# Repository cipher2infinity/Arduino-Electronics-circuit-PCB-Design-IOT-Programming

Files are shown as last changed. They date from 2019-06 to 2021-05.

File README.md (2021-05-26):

# Arduino : Electronics circuit, PCB Design & IOT Programming

You can check the course curriculum on our [WEBSITE](https://www.cipher2infinity.com/)

## Content
* Images of Datalogger
* Hardware design files and firmware files for Industrial DataLogger.
* Examples codes used in demos of all the sections of datalogger.
* hardware descreption section includes descreptions for all the hardware blocks of datalogger. 
* Libraries used in demo code

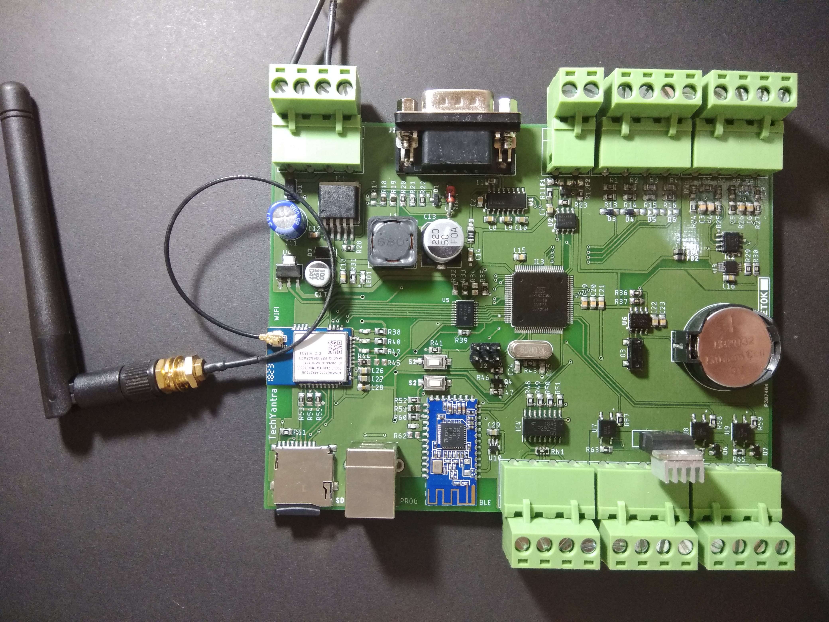
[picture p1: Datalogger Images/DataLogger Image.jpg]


## Introduction
Please check the following links for demostration of Datalogger

1. This [video](https://drive.google.com/open?id=1AglGJTn_O3K_O5rFmPPeSSnq5-zFRN2F) describes the entire PCB of Industrial Datalogger

2. This [video](https://drive.google.com/open?id=1-QjOal9vDFr6C30vdyRp-lrAA95-3nSr) gives the demostration of each and every inetrface of Industrial Datalogger

## Features
* SMPS (5V)
* LDO Regulator (3.3v)
* Relay Driver										 (2 CH)
* DC Motor Speed Controller
* 0-10 V Digital Input 					 (4 CH)
* 0-10 V Analog Input 						 (4 CH)
* 4-20 mA Receiver								 (2 CH)
* Real Time Clock
* Bluetooth Low Energy 
* WiFi Module
* SD Card Module
* RS232 Interface
* RS485 Interface
* 6 Pin ICSP Headers
* Serial Programming using UART0

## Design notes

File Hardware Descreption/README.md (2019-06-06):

ALL the sections of the datalogger are described in brief also Schematic files are included.

* Power Supply Circuit
* Atmega256 Circuit.
* DC Motor Speed Controller Circuit
* 0-10 V Digital Input Circuit
* RS485 Interface Circuit
* Relay Driver Circuit
* 0-10 V Analog Input Circuit
* RTC Circuit 
* 4-20 mA circuit
* BLE Module Circuit
* WiFi Module Circuit
* SD Card Circuit
* RS232 Interface Circuit
* Analog and Digital Isolation Circuit

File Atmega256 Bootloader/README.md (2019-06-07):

# Software to Program bootloader

You will need AVRDUDESS software to program bootloader in ATMEGA256.

Connect your ATMEGA256 to USBASP programmer, Later in AVRDUDESS software select the bootloader file also fill the fuse bytes mentioned in 
board.txt file for ATMEGA2560 (Arduino Mega) and later press the program button.

Now your microcontroller is programmed with bootloader and it is ready to use with arduino IDE and its libraries.

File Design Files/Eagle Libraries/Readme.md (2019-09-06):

Eagle libraries.zip file includes the (Eagle footprint and symbol) libraries that are downloaded from external site.

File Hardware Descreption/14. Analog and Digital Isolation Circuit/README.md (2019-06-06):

# Analog and Digital Isolation Circuit Descreption

1. FB1 and FB2 are the ferrite breads which are used to supress the noise comming from 5v to analog VCC and Analog ground to digital ground

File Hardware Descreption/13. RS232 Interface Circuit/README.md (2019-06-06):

# RS232 Interface Circuit Descreption

1. MAX232 from Maxim Corp. is a line driver IC for RS232 Interface, MAX232_TX and MAX232_RX is connected to Rx and TX pins of UART1 on ATMEGA256.
2. T1Out and R1In is connected to DB9 connector.
3. C2 and C8 are used to double the voltage from 5v to 10 volt which is in RS232 standerd range for logic '0'.
4. C10 and C9 are used to invert the voltage from +10 to -10 volt which is basically logic '1' for RS232 standerd.

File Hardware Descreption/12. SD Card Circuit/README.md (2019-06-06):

# SD Card Circuit

1. SN74LVC245 is a 8 channel transiever IC which is used to convert the voltage from 5v to 3.3v as WiFi module works on 3.3v.
2. SD Card works on 3.3 V so voltage on SPI pins are first drop down to 3.3v by using voltage level converter IC.
3. SD detect pin is pulled to 3.3v using a 10k pull up resistor to provide default logic high on SD detect pin of SD card holder.
4. This will allow us to detect whether SD card is present or not.
5. BSS138 MOSFET is used to convert the voltage on MISO pin.

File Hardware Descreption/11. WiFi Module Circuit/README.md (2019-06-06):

# WiFi Module Circuit Descreption

1. SN74LVC245 is a 8 channel transiever IC which is used to convert the voltage from 5v to 3.3v as WiFi module works on 3.3v.
2. ATWINC1510 wifi module is used for industrial IOT related applications, like to upload the datalogger parameters to web based data visualization website.
3. Led 1 shows the status whether WiFi is connected to the WiFi network or not.
4. Led 2 blinks when WiFi module recieves the data or transmits the data.
5. Led 3 light up when their is some hardware related fault.
6. BSS138 MOSFET is used to convert the voltage on MISO pin.

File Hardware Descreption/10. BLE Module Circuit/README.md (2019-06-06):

1. Between TX pin of microcontroller and Rx pin of BLE module a SN74LVC1G125 buffer is connecetd this is done to step down the voltage from 5v to 3.3v as BLE works on 3.3v.
2. Tx pin of BLE is connected to Rx pin of Atmega256, basically BLE is conneted on UART1 of Atmega256.
3. A led with current limiting resistor is connected on pin 24 of BLE, this will let you know the status of BLE whether BLE is connected or not.
4. Key pin is pulled up to 3.3v using a 10k resistor this will provide default logic high on key pin. Whnever key pin will be pulled down to ground the BLE will disconnect the connection from connected device.

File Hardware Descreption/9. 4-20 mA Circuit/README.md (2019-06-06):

# 4-20 mA Circuit Descreption

1. 100 ohm resistor after the diode are used to convert the current range to voltage range (4-20 mA to 0.4 to 2V).
2. The converted voltage is provided to the diffrential amplifier (Gain = 1) basically it is acting as a buffer. Diffrential amplifier is used to provide the impedance matching between the 4-20 mA sensor output and ADC IC's input.
3. Schottky diodes (SS14) on inverting and non inverting terminals are used to protect the OPAMP pins from overvoltage.
4. Diodes are connected before 100 ohm resistor to avoid readings when sensor is connected in wrong direction.
5. 0.1 uf capacitors are connceted on input pin and output pin of OPAMP this is done to avoid noise on input and output of OPAMP.
6. Output of OPAMP is connected to analog channel 1 and analog channel 2 of ADS1115 IC to read analog output of opamps.
7. ADS1115's I2C pins are connected to I2C pins of microcontroller to read the data for anlog channel 0 and 1.
8. ADDR pin is connected to ground this is done to assign I2C address to the IC.

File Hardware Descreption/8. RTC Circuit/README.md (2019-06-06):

# RTC Circuit Descreption

1. DS1307 RTC IC is responcible for the realtime clock feature of datalogger.
2. 32.768 KHz crystal is connected on X1 and X2 pin of RTC IC, to provide clock to the IC.
3. A CMOS battery adapter is connected on VBATT pin this will keep the clock running even if the power to datalogger is cutoff.
4. Combination of 0.1uf and 10uf capacitor is used to eliminate the noise from power supply that will avoid the data of RTC being corrupted.
5. 2.2k pull up resistors are provided to SCL and SDA pins of I2C interface this will avoid the open drain condition of the I2C hardware and will provide by default logic high on I2C pins if they are not pulled down.

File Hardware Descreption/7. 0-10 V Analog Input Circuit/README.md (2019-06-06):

# 0-10 V Analog Input Circuit Descreption

1. Pair of resistor R1-R13, R2-R14, R3-R15, R4-R16 are used to scale down the voltage (i.e. 10v will be converted to 5v) and later it is provided to the analog input pins of Atmega256.
2. AIN2, AIN3, AIN4, AIN5 are connected to A12, A13, A14 and A15 which are pins of Arduino Mega.
3. 5.1 V zener diodes are used to supress the applied input voltage if it is greater than 10v, that will protect the analog pins of Atmega256.

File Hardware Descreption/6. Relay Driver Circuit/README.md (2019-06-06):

# Relay Driver Circuit Descreption
1. This circuit is used to control the relay which will be connected externally.
2. This circuit uses EL357 optocoupler IC which is used to isolate the microcontroller pin from the output circuitry.
4. BC817 is a NPN transistor which is used to drive the relay, it can provide maximum of 600 mA which is more than sufficient to drive a relay.
5. SS14 schottky diode is used to provide the protection form back EMF.
6. R64 and R65 are used to limit the current flowing from the base of BC817 transistor.
7. R58 and R59 are the current limiting resistor for the led of optocoupler.
8. Relay_1 and Relay_2 pins are connected to GPIO pin of the microcontroller.

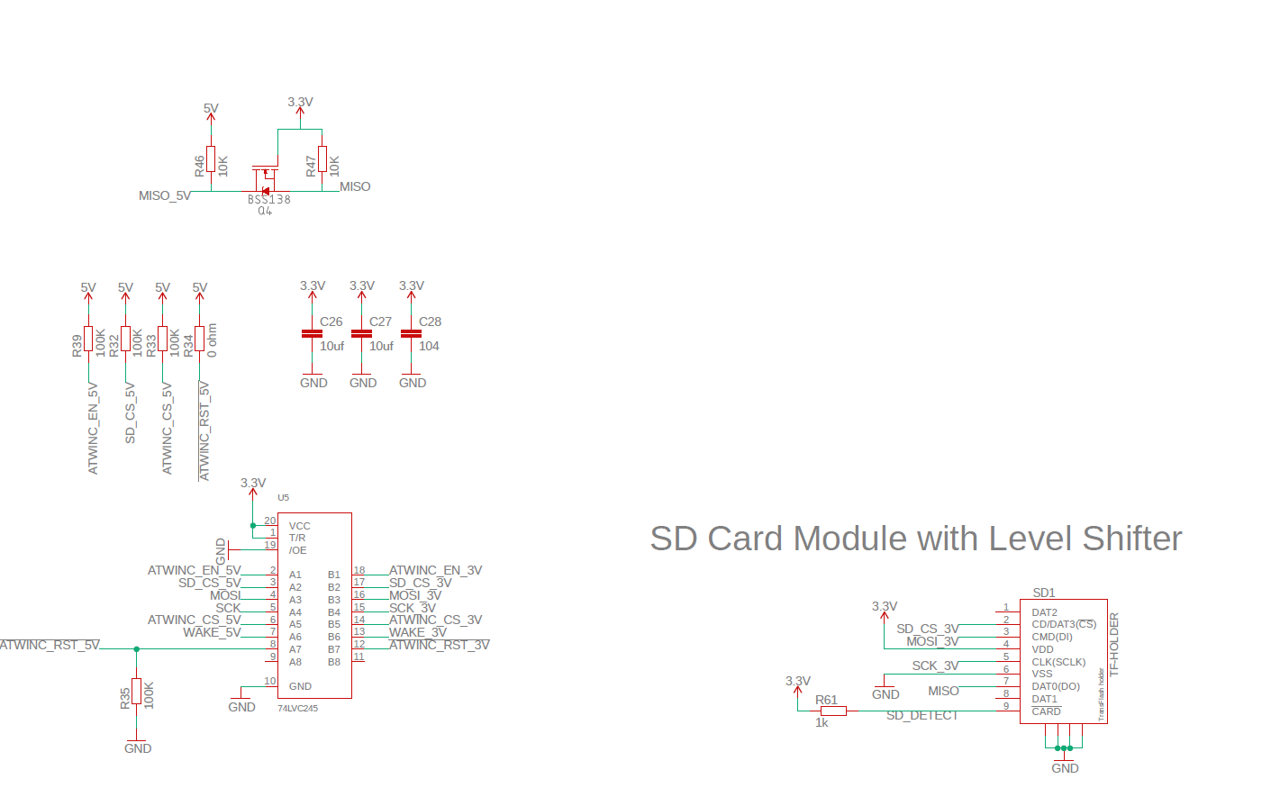
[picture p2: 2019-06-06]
Hardware Descreption/12. SD Card Circuit/SD Card Circuit.png

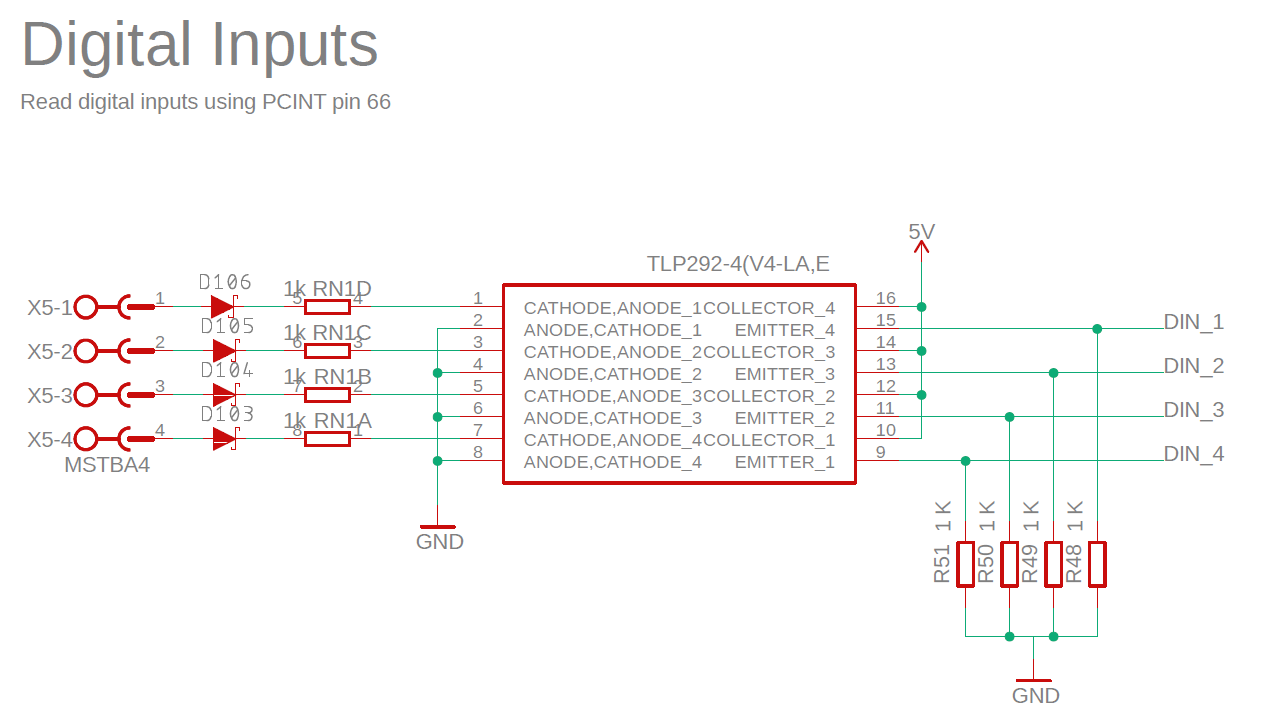
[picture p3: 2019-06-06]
Hardware Descreption/4. 0-10 V Digital Inputs Circuit/0-10 V Digital Input Circuit.png

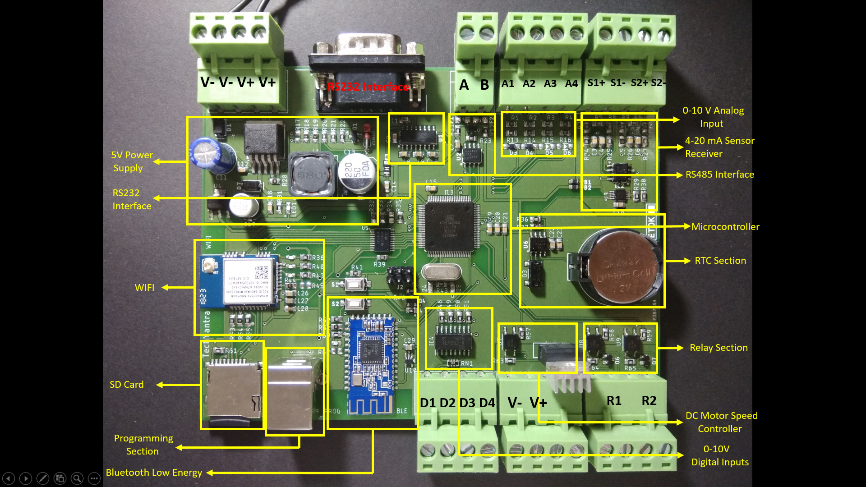
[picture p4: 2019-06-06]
Datalogger Images/Data Logger Board overview.png

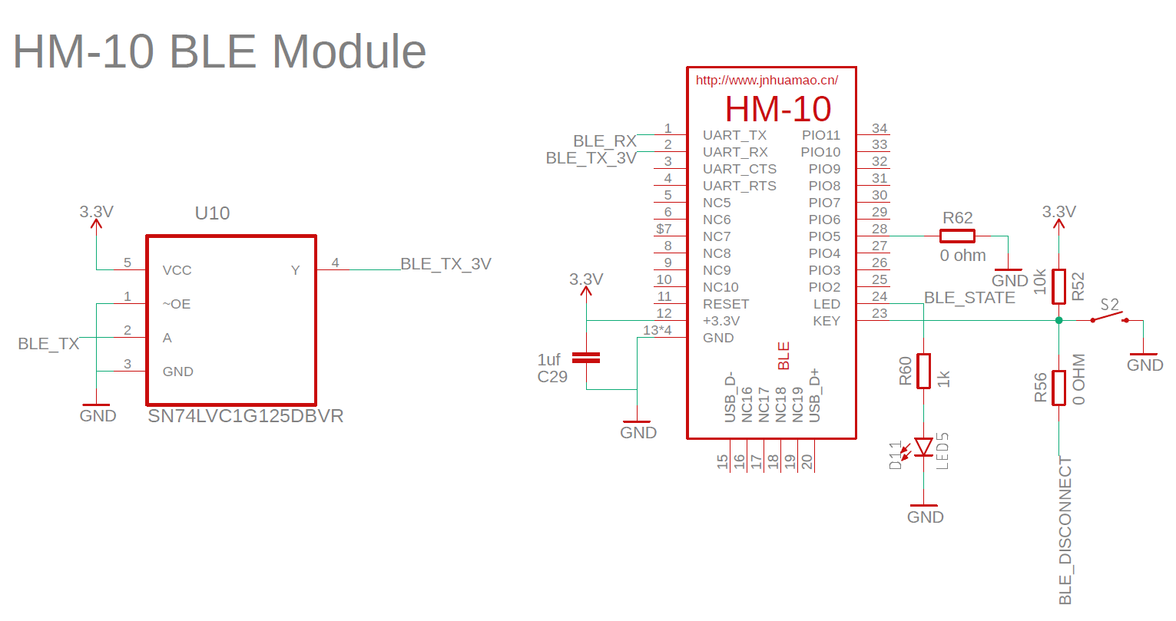
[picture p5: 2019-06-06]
Hardware Descreption/10. BLE Module Circuit/BLE Module Circuit.png

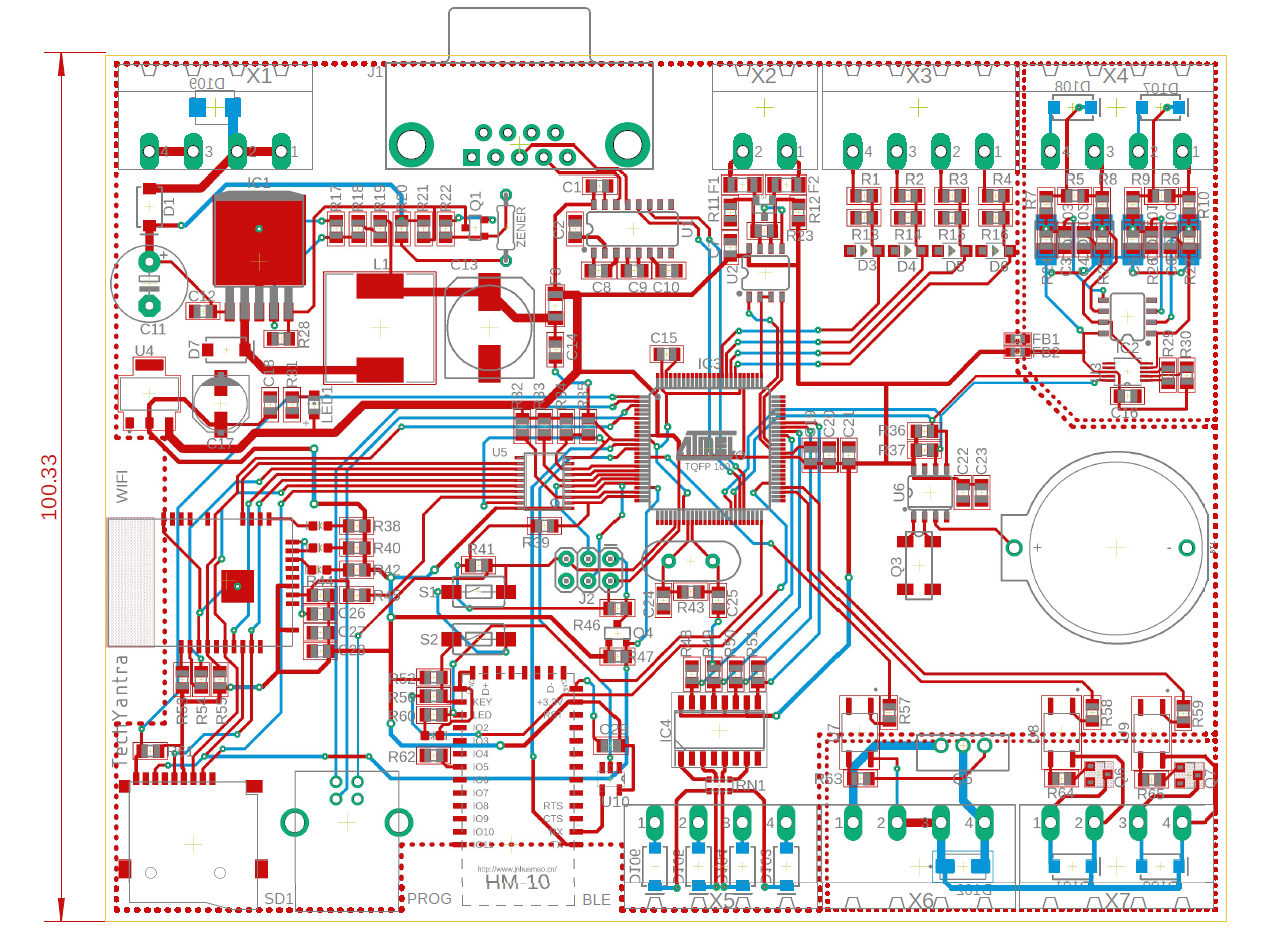
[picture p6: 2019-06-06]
Design Files/DataLogger Layout.png

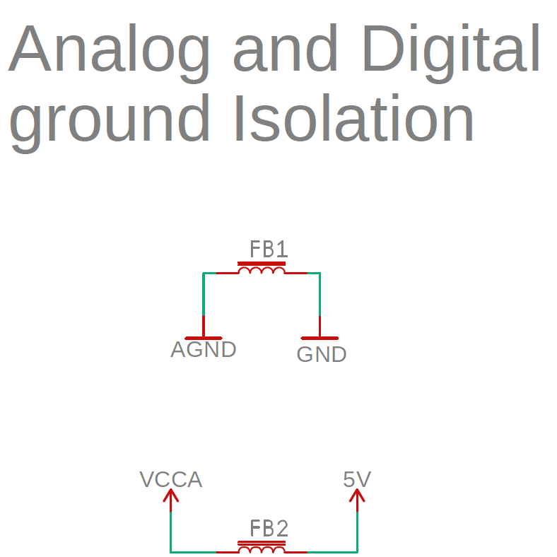
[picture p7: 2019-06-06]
Hardware Descreption/14. Analog and Digital Isolation Circuit/Analog and Digital Isolation.png

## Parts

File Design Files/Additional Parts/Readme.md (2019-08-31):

* Following components or module are used during the course

# Modules

* USB to TTL converter
* RS232 to TTL converter
* RS485 to TTL converter
* USBASP programmer
* 10 k potentiometer
* DS1307 RTC module
* ADS1115 16 bit ADC module
* 12v DC motor
* 12v Relay
* Submercible pump
* Salae Logic Analyzer
* SD card
* Multimeter
* 4-20mA transmitter

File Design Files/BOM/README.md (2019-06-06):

* Bill of material file includes all the components used in this datalogger

# Main IC's Used on Datalogger

* LM2596-5.0 SMPS
* AMS1117-3.3 LDO Regulator
* ATMEGA2560 Microcontroller
* EL357 Optocoupler
* TLP492-4 4 Channel optocoupler 
* MAX485 RS485 Driver
* DS1307 RTC
* ADS1115 16 bit 4 channel ADC
* LM358 OPAMP
* SN74LVC1G125 Single channel buffer
* HM-10 BLE Module
* SN74LVC1G245 Octal transievr
* ATWINC1510 WiFi Module
* MAX232 Line Driver

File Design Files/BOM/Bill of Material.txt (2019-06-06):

Partlist exported from E:/Projects/Data Logger V3.0/Data Logger V3.0/Data Logger V3.1.sch at 6/3/2019 9:30 AM

Part   Value                               Device                              Package                      Description                                                                                                                                                                                                                                       AVAILABILITY DESCRIPTION                                                                                      HEIGHT MANUFACTURER_NAME       MANUFACTURER_PART_NUMBER MF                          MOUSER_PART_NUMBER MOUSER_PRICE-STOCK                                                   MP               MPN                            OC_FARNELL OC_NEWARK PACKAGE                          PRICE PROD_ID     RS_PART_NUMBER RS_PRICE-STOCK                                               SF_SKU    SPICEMODEL SPICEPREFIX VALUE        
BLE    HM-10-BOARD                         HM-10-BOARD                         26.9X13X2.2_BOARD            HM Bluetooth module use TI CC2540 or CC2541, Master and slave roles in one, transmission version and remote control version and PIO state acquisition functions in one, Support the AT command modify module parameters, Convenient and flexible.                                                                                                                                                                                                                                                                                                                                                                                                                                                                                                                                             
BT1                                        BATTERY-20MM_PTH                    BATTCOM_20MM_PTH             Battery - Single Cell                                                                                                                                                                                                                                                                                                                                                                                                                                                                                                                                                                                                                                   BATT-09031                                                                              PRT-00783                                     
C1     0.1uf                               C-EUC0805                           C0805                        CAPACITOR, European symbol                                                                                                                                                                                                                                                                                                                                                                                                                                                                                                                                                                                                                                                                                                                                           C                        
C2     0.1uf                               C-EUC0805                           C0805                        CAPACITOR, European symbol                                                                                                                                                                                                                                                                                                                                                                                                                                                                                                                                                                                                                                                                                                                                           C                        
C3     0.1uf                               C-EUC0805                           C0805                        CAPACITOR, European symbol                                                                                                                                                                                                                                                                                                                                                                                                                                                                                                                                                                                                                                                                                                                                           C                        
C4     0.1uf                               C-EUC0805                           C0805                        CAPACITOR, European symbol                                                                                                                                                                                                                                                                                                                                                                                                                                                                                                                                                                                                                                                                                                                                           C                        
C5     0.1uf                               C-EUC0805                           C0805                        CAPACITOR, European symbol                                                                                                                                                                                                                                                                                                                                                                                                                                                                                                                                                                                                                                                                                                                                           C                        
C6     0.1uf                               C-EUC0805                           C0805                        CAPACITOR, European symbol                                                                                                                                                                                                                                                                                                                                                                                                                                                                                                                                                                                                                                                                                                                                           C                        
C7     104                                 C-EUC0805                           C0805                        CAPACITOR, European symbol                                                                                                                                                                                                                                                                                                                                                                                                                                                                                                                                                                                                                                                                                                                                           C                        
C8     0.1uf                               C-EUC0805                           C0805                        CAPACITOR, European symbol                                                                                                                                                                                                                                                                                                                                                                                                                                                                                                                                                                                                                                                                                                                                           C                        
C9     0.1uf                               C-EUC0805                           C0805                        CAPACITOR, European symbol                                                                                                                                                                                                                                                                                                                                                                                                                                                                                                                                                                                                                                                                                                                                           C                        
C10    0.1uf                               C-EUC0805                           C0805                        CAPACITOR, European symbol                                                                                                                                                                                                                                                                                                                                                                                                                                                                                                                                                                                                                                                                                                                                           C                        
C11    470uf                               CPOL-USE5-8.5                       E5-8,5                       POLARIZED CAPACITOR, American symbol                                                                                                                                                                                                                                                                                                                                                                                                                                                                                                                                                                                                                                                                                                                                                          
C12    104                                 C-EUC0805                           C0805                        CAPACITOR, European symbol                                                                                                                                                                                                                                                                                                                                                                                                                                                                                                                                                                                                                                                                                                                                           C                        
C13    220uf                               CPOL-US150CLZ-1014                  150CLZ-1014                  POLARIZED CAPACITOR, American symbol                                                                                                                                                                                                                                                                                                                                                                                                                                                                                                                                                                                                                                                                                                                                                          
C14    104                                 C-EUC0805                           C0805                        CAPACITOR, European symbol                                                                                                                                                                                                                                                                                                                                                                                                                                                                                                                                                                                                                                                                                                                                           C                        
C15    104                                 C-EUC0805                           C0805                        CAPACITOR, European symbol                                                                                                                                                                                                                                                                                                                                                                                                                                                                                                                                                                                                                                                                                                                                           C                        
C16    0.1uf                               C-EUC0805                           C0805                        CAPACITOR, European symbol                                                                                                                                                                                                                                                                                                                                                                                                                                                                                                                                                                                                                                                                                                                                           C                        
C17    100uF                               100UF-POLAR-25V-20%(ELEC)           PANASONIC_D                  100µF polarized capacitors                                                                                                                                                                                                                                                                                                                                                                                                                                                                                                                                                                                                                              CAP-12547                                                                                                                100uF        
C18    104                                 C-EUC0805                           C0805                        CAPACITOR, European symbol                                                                                                                                                                                                                                                                                                                                                                                                                                                                                                                                                                                                                                                                                                                                           C                        
C19    104                                 C-EUC0805                           C0805                        CAPACITOR, European symbol                                                                                                                                                                                                                                                                                                                                                                                                                                                                                                                                                                                                                                                                                                                                           C                        
C20    104                                 C-EUC0805                           C0805                        CAPACITOR, European symbol                                                                                                                                                                                                                                                                                                                                                                                                                                                                                                                                                                                                                                                                                                                                           C                        
C21    104                                 C-EUC0805                           C0805                        CAPACITOR, European symbol                                                                                                                                                                                                                                                                                                                                                                                                                                                                                                                                                                                                                                                                                                                                           C                        
C22    10uf                                C-EUC0805                           C0805                        CAPACITOR, European symbol                                                                                                                                                                                                                                                                                                                                                                                                                                                                                                                                                                                                                                                                                                                                           C                        
C23    104                                 C-EUC0805                           C0805                        CAPACITOR, European symbol                                                                                                                                                                                                                                                                                                                                                                                                                                                                                                                                                                                                                                                                                                                                           C                        
C24    104                                 C-EUC0805                           C0805                        CAPACITOR, European symbol                                                                                                                                                                                                                                                                                                                                                                                                                                                                                                                                                                                                                                                                                                                                           C                        
C25    104                                 C-EUC0805                           C0805                        CAPACITOR, European symbol                                                                                                                                                                                                                                                                                                                                                                                                                                                                                                                                                                                                                                                                                                                                           C                        
C26    10uf                                C-EUC0805                           C0805                        CAPACITOR, European symbol                                                                                                                                                                                                                                                                                                                                                                                                                                                                                                                                                                                                                                                                                                                                           C                        
C27    10uf                                C-EUC0805                           C0805                        CAPACITOR, European symbol                                                                                                                                                                                                                                                                                                                                                                                                                                                                                                                                                                                                                                                                                                                                           C                        
C28    104                                 C-EUC0805                           C0805                        CAPACITOR, European symbol                                                                                                                                                                                                                                                                                                                                                                                                                                                                                                                                                                                                                                                                                                                                           C                        
C29    1uf                                 C-EUC0805                           C0805                        CAPACITOR, European symbol                                                                                                                                                                                                                                                                                                                                                                                                                                                                                                                                                                                                                                                                                                                                           C                        
D1     3A/40V/500mV                        DIODE-SCHOTTKY-B340A                SMA-DIODE                    Schottky diode                                                                                                                                                                                                                                                                                                                                                                                                                                                                                                                                                                                                                                          DIO-09886                                                                                                                3A/40V/500mV 
D2     SM712                               CDSOT23-SM712                       SOT-23-3                     Bourns CDSOT23-SM712                                                                                                                                                                                                                              Unavailable   Diode, Smt Tvs Array, 7vrwm & 12vrwm, Sot23 Package                                                                                                     Bourns                                                                                                              CDSOT23-SM712                                                        SOT-23 Bourns                    None
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

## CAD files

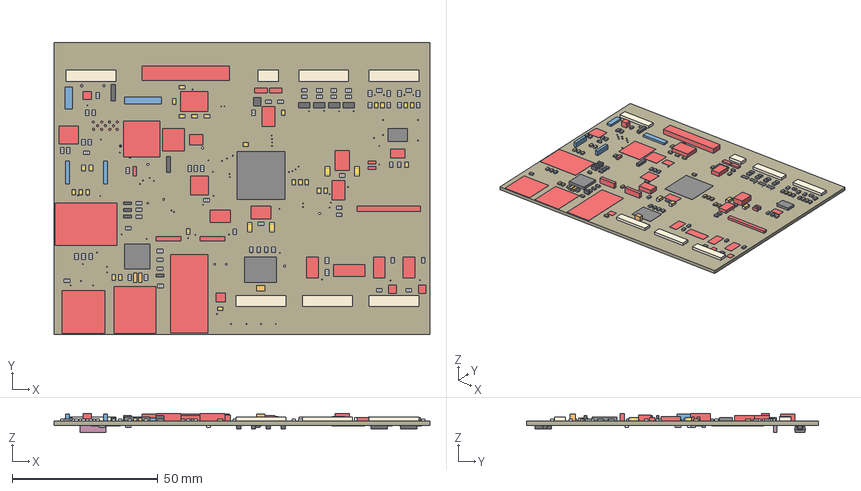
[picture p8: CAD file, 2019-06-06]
Design Files/Mechanical Design Files/Data Logger V2.stp
129.2 x 100.3 x 6.68 mm
Board
HM-10-BOARD
22p x 4
SMBJ26CA
SM712
SS14 x 4
ATMEGA2560-16AU
68uh
3.3uh
BSS138
TRANSISTOR-NPN x 2
16M
1 K x 44
0ohm x 26
TF-HOLDER
LM2596SX-ADJ/NOPB
AMS1117-3.3
74LVC245
ADS1115IDGST
SN74LVC1G125DBVR x 2
ATWINC1500_MR210PB
32.768kHz
MINISMDC050F-2
TIP120
M7
EL357N(A)(TA)-G x 3
TLP292-4(V4-LA,E
SMD-DIODE-ZENER-5.1V-500MW(SOD-123) x 4
BATTCOM_20MM_PTH
470uf
220uf
100uF x 2
3A/40V/500mV x 10
GREEN x 4
6V/0.5A x 2
30Ω/1.8A x 2
OP-AMP
FT232RL
DB9_MALE
CHIPLED_0805
500mA/300V
1k
Red x 2
MOMENTARY-SWITCH-SPST-SMD-6.0X3.5MM x 2
DS1307Z
MAX3485CSA
MAX3232
MSTBA4 x 6
0204/7
MSTBA2
MC-306
AVR_SPI_PROG_3X2PTH

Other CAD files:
Design Files/Mechanical Design Files/Data Logger.stl
Design Files/Mechanical Design Files/Data Logger V2.obj

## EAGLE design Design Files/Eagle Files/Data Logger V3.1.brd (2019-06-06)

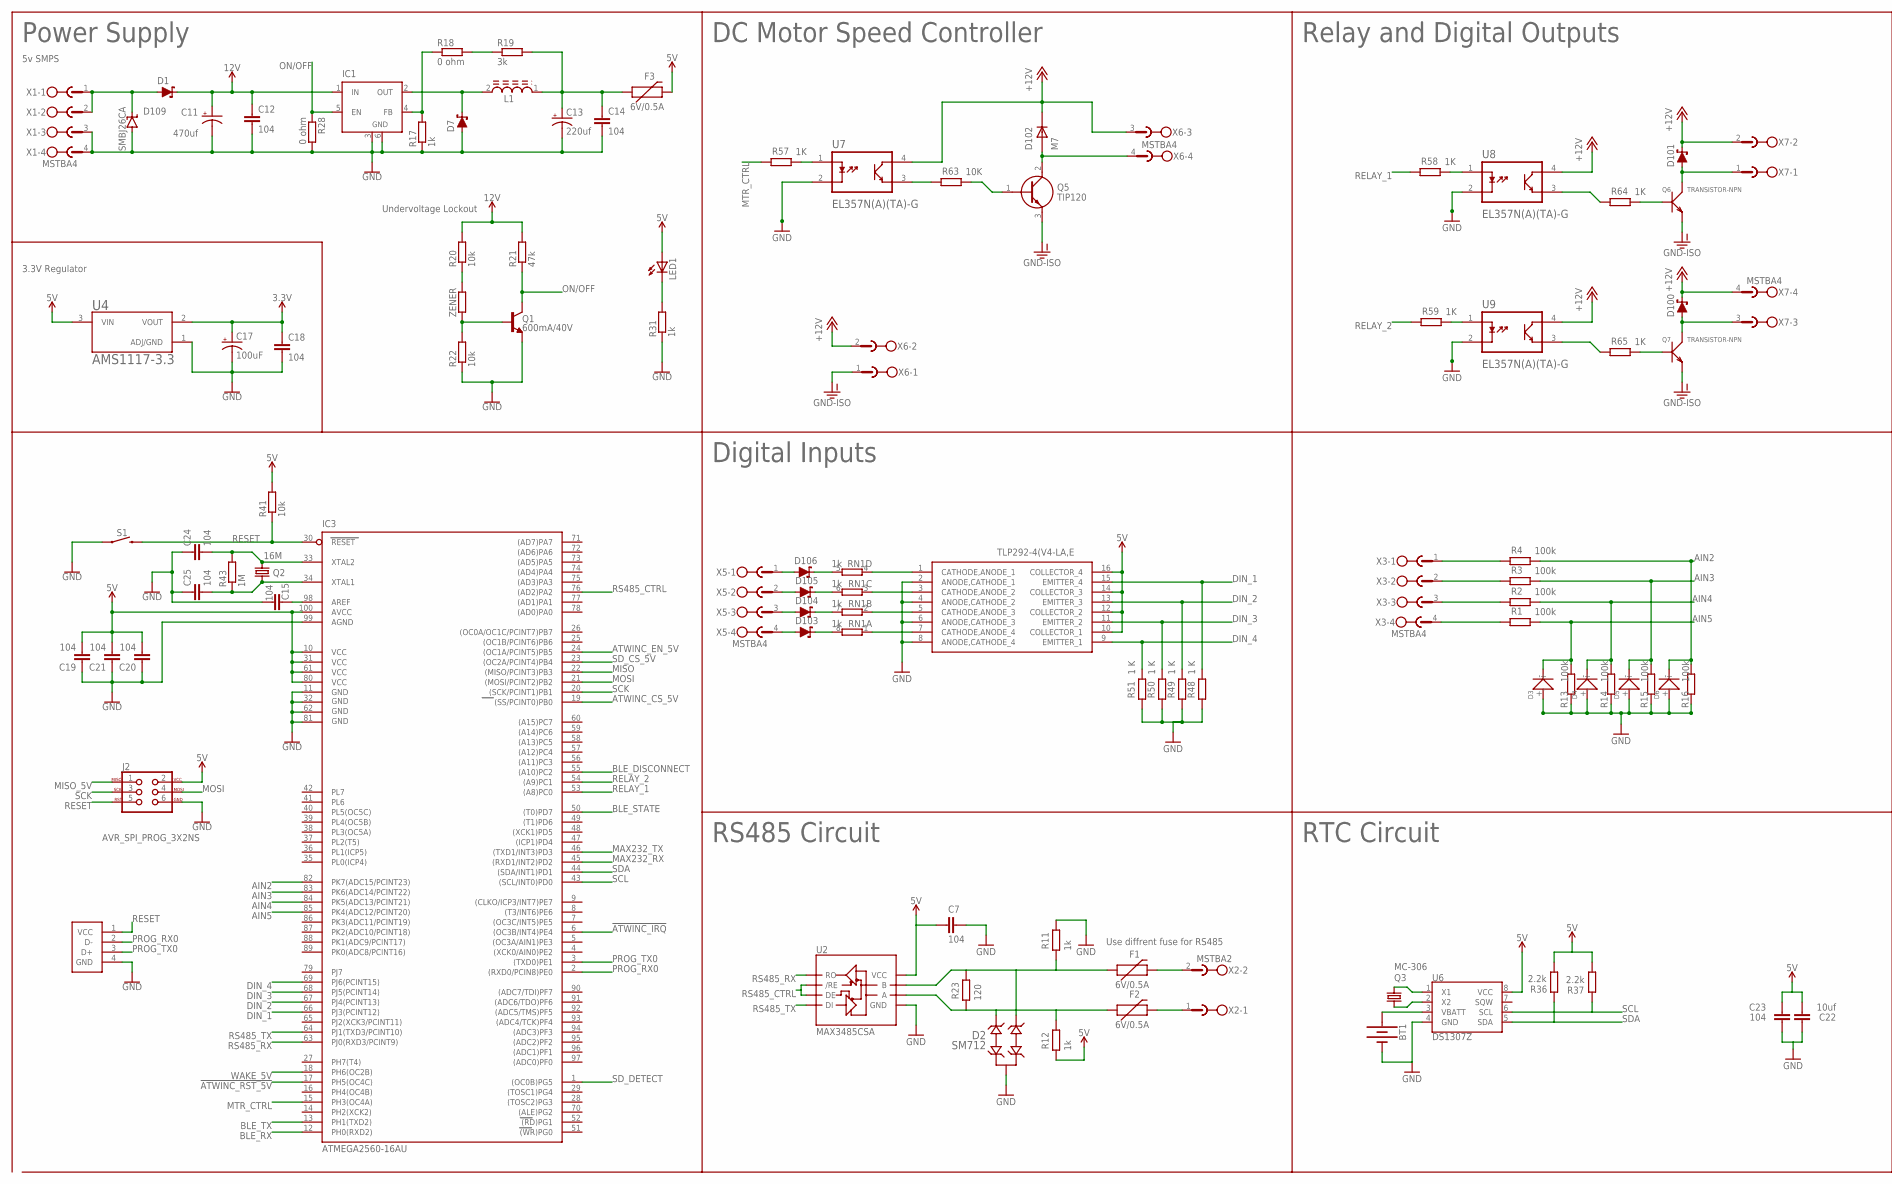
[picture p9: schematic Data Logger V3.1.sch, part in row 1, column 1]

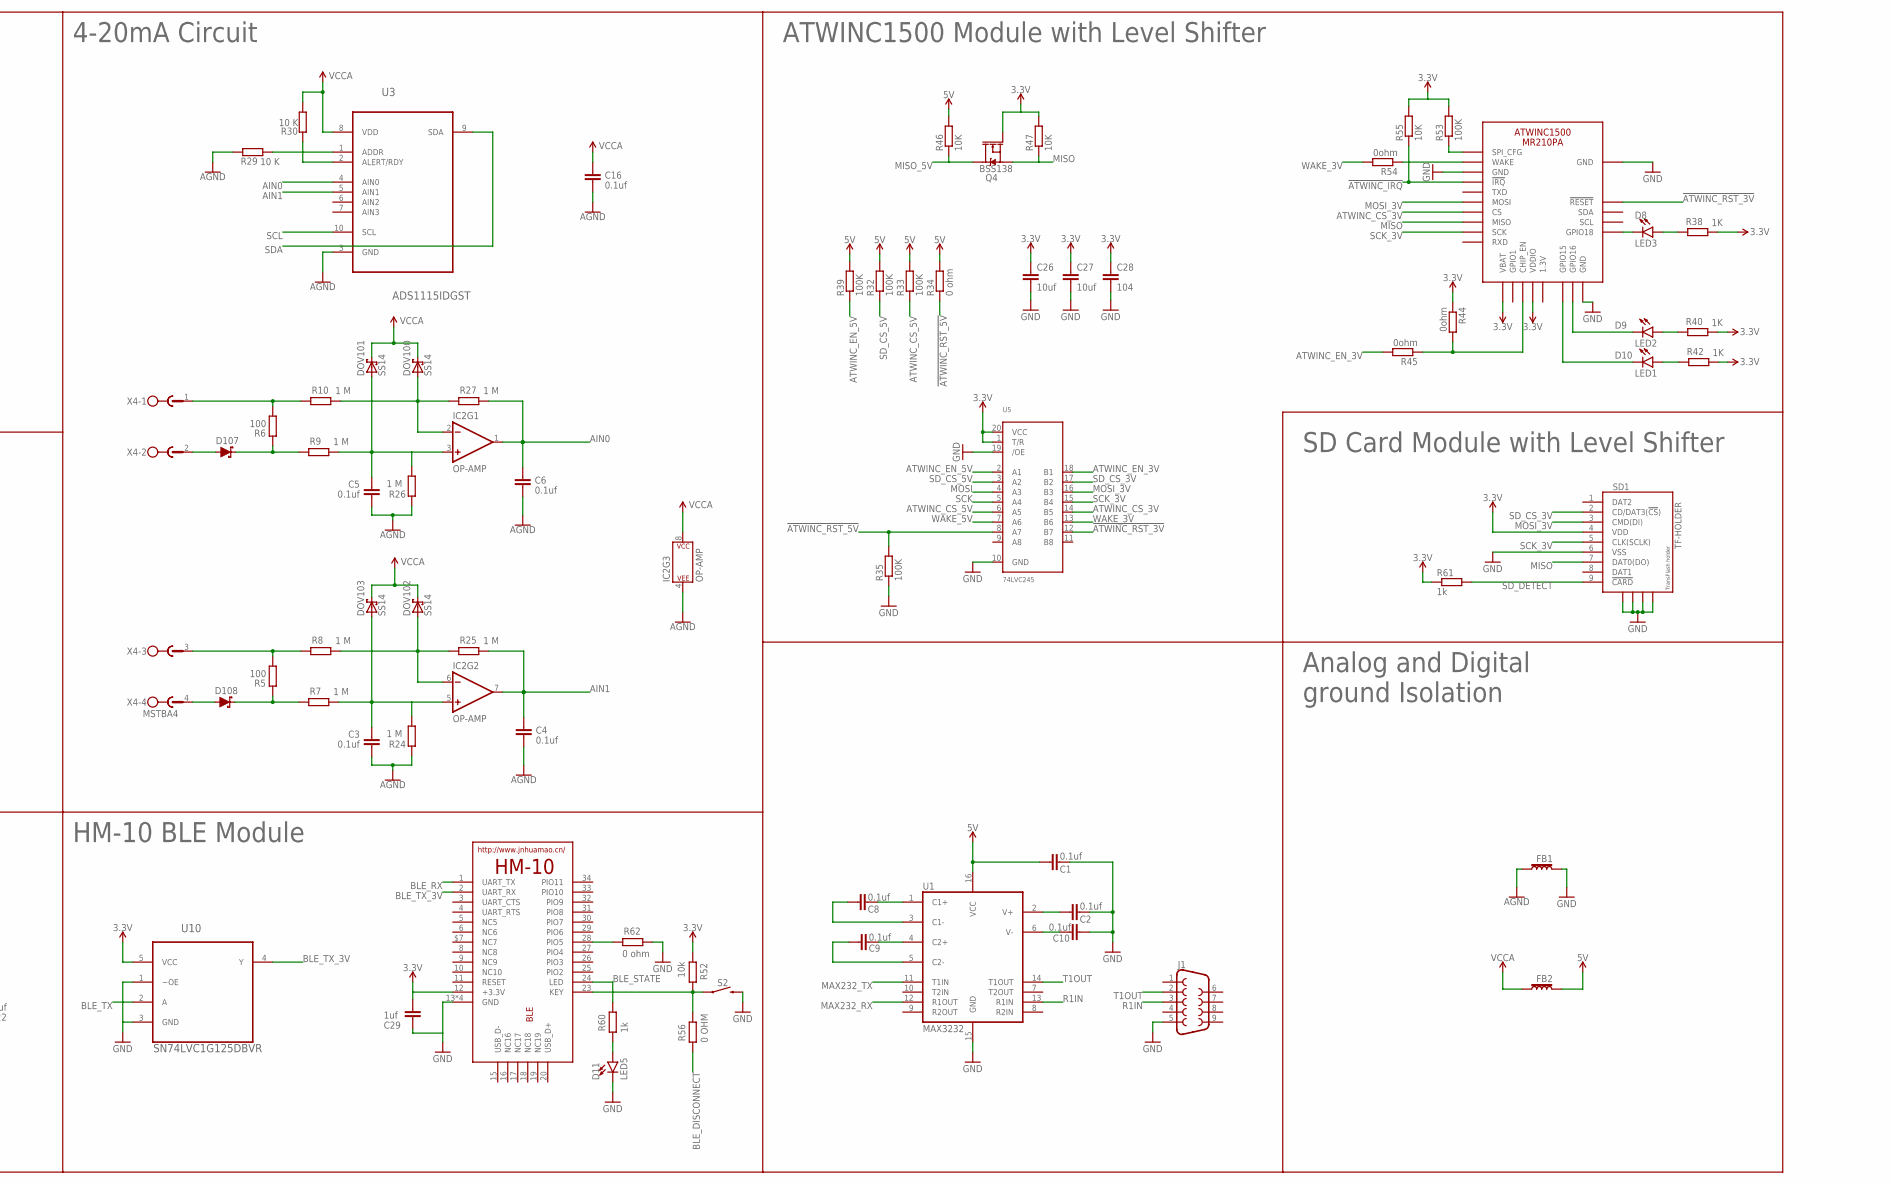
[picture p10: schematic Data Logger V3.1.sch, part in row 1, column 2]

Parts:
BLE: HM-10-BOARD; 26.9X13X2.2_BOARD
BT1: BATTERY-20MM_PTH; BATTCOM_20MM_PTH
C1, C2, C3, C4, C5, C6, C8, C9, C10, C16: 0.1uf; C0805
C7, C12, C14, C15, C18, C19, C20, C21, C23, C24, C25, C28: 104; C0805
C11: 470uf; E5-8,5
C13: 220uf; 150CLZ-1014
C17: 100uF; PANASONIC_D
C22, C26, C27: 10uf; C0805
C29: 1uf; C0805
D1, D7, D100, D101, D103, D104, D105, D106, D107, D108: 3A/40V/500mV; SMA-DIODE
D2: SM712; SOT-23-3
D3, D4, D5, D6: SMD-DIODE-ZENER-5.1V-500MW(SOD-123); SOD-123
D8: LED3; LED-0603
D9: LED2; LED-0603
D10: LED1; LED-0603
D11: LED5; LED-0603
D102: M7; DIOM505270X240
D109: SMBJ26CA; SMBJ
DOV100, DOV101, DOV102, DOV103: SS14; DO-214AC
F1, F2, F3: 6V/0.5A; 1206
FB1, FB2: 30Ω/1.8A; 0603
IC1: LM2596S; TO263-5
IC2: OP-AMP; SO08
IC3: ATMEGA2560-16AU; TQFP100
IC4: TLP292-4(V4-LA,E; SOIC127P700X230-16N
J1: DB9MALE; DB9_MALE
J2: AVR_SPI_PROG_3X2NS; 2X3-NS
L1: SRR1260-680M; INDP125125X600N
LED1: LEDCHIP-LED0805; CHIP-LED0805
PROG: 61400416121
Q1: 600mA/40V; SOT23-3
Q2: 16M; HC49US
Q3: MC-306
Q4: BSS138; SOT23-3
Q5: TIP120; TO220
Q6, Q7: TRANSISTOR-NPN; SOT-23
R1, R2, R3, R4, R13, R14, R15, R16: 100k; R0805
R5, R6: 100; R0805
R7, R8, R9, R10, R24, R25, R26, R27: 1 M; R0805
R11, R12, R17, R31, R60, R61: 1k; R0805
R18, R28, R34, R62: 0 ohm; R0805
R19: 3k; R0805
R20, R22, R41, R52: 10k; R0805
R21: 47k; R0805
R23: 120; R0805
R29, R30: 10 K; R0805
R32, R33, R35, R39, R53: 100K; R0805
R36, R37: 2.2k; R0805
R38, R40, R42, R57, R58, R59, R64, R65: 1K; R0805
R43: 1M; R0805
R44, R45, R54: 0ohm; R0805
R46, R47, R55, R63: 10K; R0805
R48, R49, R50, R51: 1 K; R0805
R56: 0 OHM; R0805
RN1: 1k; CAY16
S1, S2: MOMENTARY-SWITCH-SPST-SMD-6.0X3.5MM; TACTILE_SWITCH_SMD_6.0X3.5MM
SD1: TF-HOLDER; TF-PULL
U1: MAX3232; SO16
U2: MAX3485CSA; SO08
U3: ADS1115IDGST; SOP50P490X110-10N
U4: AMS1117-3.3; SOT229P700X180-4N
U5: 74LVC245; TSSOP20
U6: DS1307Z; SO08-0.15
U7, U8, U9: EL357N(A)(TA)-G; SOP254P700X200-4N
U10: SN74LVC1G125DBVR; SOT95P280X145-5N
WIFI: ATWINC1500_MR210PB; ATWINC1500_MR210PA
X1, X3, X4, X5, X6, X7: MSTBA4
X2: MSTBA2
ZENER: R0204/7; 0204/7

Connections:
3.3V: BLE.12 (+3.3V), C17.+, C18.1, C26.1, C27.1, C28.1, C29.2, Q4.1 (G), R38.1, R40.1, R42.1, R44.1, R47.2, R52.2, R53.2, R55.2, R61.1, SD1.4 (VDD), U4.2 (VOUT), U5.1 (T/R), U5.20 (VCC), U10.5 (VCC), WIFI.J20 (VBAT), WIFI.J23 (VDDIO)
5V: C1.2, C7.1, C19.2, C20.2, C21.2, C22.2, C23.2, F3.2, FB2.2, IC3.10 (VCC), IC3.31 (VCC1), IC3.61 (VCC2), IC3.80 (VCC3), IC3.100 (AVCC), IC4.10 (COLLECTOR_1), IC4.12 (COLLECTOR_2), IC4.14 (COLLECTOR_3), IC4.16 (COLLECTOR_4), J2.2, LED1.A, R12.2, R32.2, R33.2, R34.2, R36.1, R37.1, R39.2, R41.2, R46.2, U1.16 (VCC), U2.8 (VCC), U4.3 (VIN), U6.8 (VCC)
12V: C11.+, C12.1, D1.C, IC1.1 (IN), R20.2, R21.2
!ATWINC_IRQ: IC3.6 ((OC3B/INT4)PE4), R55.1, WIFI.J13 (!IRQ)
!ATWINC_RST_3V: U5.12 (B7), WIFI.J4 (!RESET)
!ATWINC_RST_5V: IC3.17 (PH5(OC4C)), R34.1, R35.2, U5.8 (A7)
+12V: D100.C, D101.C, D102.C, U7.4 (C), U8.4 (C), U9.4 (C), X6.2, X6.3, X7.2, X7.4
AGND: C3.1, C4.1, C5.1, C6.1, C16.1, FB1.1, IC2.4 (P$V-), R24.2, R26.2, R29.1, U3.3 (GND)
AIN0: C6.2, IC2.1 (OUT), R27.1, U3.4 (AIN0)
AIN1: C4.2, IC2.7 (OUT), R25.1, U3.5 (AIN1)
AIN2: D6.-, IC3.82 (PK7(ADC15/PCINT23)), R4.1, R16.1
AIN3: D5.-, IC3.83 (PK6(ADC14/PCINT22)), R3.1, R15.1
AIN4: D4.-, IC3.84 (PK5(ADC13/PCINT21)), R2.1, R14.1
AIN5: D3.-, IC3.85 (PK4(ADC12/PCINT20)), R1.1, R13.1
AREF: C15.1, IC3.98 (AREF)
ATWINC_CS_3V: U5.14 (B5), WIFI.J16 (CS)
ATWINC_CS_5V: IC3.19 ((SS/PCINT0)PB0), R33.1, U5.6 (A5)
ATWINC_EN_3V: R45.2, U5.18 (B1)
ATWINC_EN_5V: IC3.24 ((OC1A/PCINT5)PB5), R39.1, U5.2 (A1)
BLE_DISCONNECT: IC3.55 ((A10)PC2), R56.2
BLE_RX: BLE.1 (UART_TX), IC3.12 (PH0(RXD2))
BLE_STATE: BLE.24 (LED), IC3.50 ((T0)PD7), R60.1
BLE_TX: IC3.13 (PH1(TXD2)), U10.2 (A)
BLE_TX_3V: BLE.2 (UART_RX), U10.4 (Y)
DIN_1: IC3.66 (PJ3(PCINT12)), IC4.15 (EMITTER_4), R48.1
DIN_2: IC3.67 (PJ4(PCINT13)), IC4.13 (EMITTER_3), R49.1
DIN_3: IC3.68 (PJ5(PCINT14)), IC4.11 (EMITTER_2), R50.1
DIN_4: IC3.69 (PJ6(PCINT15)), IC4.9 (EMITTER_1), R51.1
GND: BLE.13 (GND), BLE.14 (GND), BLE.21 (GND), BLE.22 (GND), BT1.2 (-), C1.1, C2.1, C7.2, C10.1, C11.-, C12.2, C13.-, C14.2, C15.2, C17.-, C18.2, C19.1, C20.1, C21.1, C22.1, C23.1, C24.1, C25.1, C26.2, C27.2, C28.2, C29.1, D2.3 (GND), D3.+, D4.+, D5.+, D6.+, D7.A, D11.C, D109.A, FB1.2, IC1.3 (GND), IC1.6 (GND), IC3.11 (GND), IC3.32 (GND1), IC3.62 (GND2), IC3.81 (GND3), IC3.99 (AGND), IC4.2 (ANODE,CATHODE_1), IC4.4 (ANODE,CATHODE_2), IC4.6 (ANODE,CATHODE_3), IC4.8 (ANODE,CATHODE_4), J1.5, J2.6, PROG.4 (GND), Q1.2 (E), R11.1, R13.2, R14.2, R15.2, R16.2, R17.1, R22.1, R28.2, R31.1, R35.1, R48.2, R49.2, R50.2, R51.2, R62.1, S1.1, S2.2, SD1.6 (VSS), SD1.S1, SD1.S2, SD1.S3, SD1.S4, U1.15 (GND), U2.5 (GND), U4.1 (ADJ/GND), U5.10 (GND), U5.19 (/OE), U6.4 (GND), U7.2 (K), U8.2 (K), U9.2 (K), U10.1 (~OE), U10.3 (GND), WIFI.J9 (GND), WIFI.J12 (GND), WIFI.J28 (GND), WIFI.MTGND (GND), X1.3, X1.4
GND-ISO: Q5.3 (E), Q6.2 (E), Q7.2 (E), X6.1
MAX232_RX: IC3.45 ((RXD1/INT2)PD2), U1.12 (R1OUT)
MAX232_TX: IC3.46 ((TXD1/INT3)PD3), U1.11 (T1IN)
MISO: IC3.22 ((MISO/PCINT3)PB3), Q4.2 (S), R47.1, SD1.7 (DAT0(DO)), WIFI.J17 (MISO)
MISO_5V: J2.1, Q4.3 (D), R46.1
MOSI: IC3.21 ((MOSI/PCINT2)PB2), J2.4, U5.4 (A3)
MOSI_3V: SD1.3 (CMD(DI)), U5.16 (B3), WIFI.J15 (MOSI)
MTR_CTRL: IC3.15 (PH3(OC4A)), R57.2
unnamed: C13.+, C14.1, F3.1, L1.1, R19.2
unnamed: D8.C, WIFI.J1 (GPIO18)
unnamed: R58.1, U8.1 (A)
unnamed: R4.2, X3.1
unnamed: D9.C, WIFI.J27 (GPIO16)
unnamed: D10.C, WIFI.J26 (GPIO15)
unnamed: R53.1, WIFI.J10 (SPI_CFG)
unnamed: D10.A, R42.2
unnamed: D9.A, R40.2
unnamed: D8.A, R38.2
unnamed: D2.2 (IO2), F1.1, R11.2, R23.1, U2.7 (B)
unnamed: D2.1 (IO1), F2.1, R12.1, R23.2, U2.6 (A)
unnamed: R3.2, X3.2
unnamed: BT1.1 (+), U6.3 (VBATT)
unnamed: F1.2, X2.2
unnamed: F2.2, X2.1
unnamed: Q3.1, U6.1 (X1)
unnamed: Q3.4 (2), U6.2 (X2)
unnamed: BLE.28 (PIO5), R62.2
unnamed: R2.2, X3.3
unnamed: R59.1, U9.1 (A)
unnamed: R1.2, X3.4
unnamed: R44.2, R45.1, WIFI.J22 (CHIP_EN)
unnamed: R54.1, WIFI.J11 (WAKE)
unnamed: BLE.23 (KEY), R52.1, R56.1, S2.1
unnamed: R30.1, U3.2 (ALERT/RDY)
unnamed: R29.2, U3.1 (ADDR)
unnamed: C5.2, DOV101.A, IC2.3 (+IN), R9.1, R26.1
unnamed: R63.2, U7.3 (E)
unnamed: DOV100.A, IC2.2 (-IN), R10.1, R27.2
unnamed: R6.1, R10.2, X4.1
unnamed: D11.A, R60.2
unnamed: D108.A, X4.4
unnamed: Q5.1 (B), R63.1
unnamed: R64.2, U8.3 (E)
unnamed: D108.C, R5.2, R7.2
unnamed: D107.A, X4.2
unnamed: D103.A, X5.4
unnamed: D103.C, RN1.8 (2)
unnamed: D104.C, RN1.7 (2)
unnamed: D104.A, X5.3
unnamed: D105.A, X5.2
unnamed: C3.2, DOV103.A, IC2.5 (+IN), R7.1, R24.1
unnamed: DOV102.A, IC2.6 (-IN), R8.1, R25.2
unnamed: D105.C, RN1.6 (2)
unnamed: D107.C, R6.2, R9.2
unnamed: R65.2, U9.3 (E)
unnamed: R5.1, R8.2, X4.3
unnamed: D106.C, RN1.5 (2)
unnamed: D106.A, X5.1
unnamed: R20.1, ZENER.2
unnamed: R57.1, U7.1 (A)
unnamed: D102.A, Q5.2 (C), X6.4
unnamed: D7.C, IC1.2 (OUT), L1.2
unnamed: D1.A, D109.C, X1.1, X1.2
unnamed: IC1.4 (FB), R17.2, R18.1
unnamed: R18.2, R19.1
unnamed: Q1.1 (B), R22.2, ZENER.1
unnamed: LED1.C, R31.2
unnamed: C24.2, IC3.33 (XTAL2), Q2.2, R43.2
unnamed: C25.2, IC3.34 (XTAL1), Q2.1, R43.1
unnamed: IC4.1 (CATHODE,ANODE_1), RN1.4 (1)
unnamed: IC4.3 (CATHODE,ANODE_2), RN1.3 (1)
unnamed: IC4.5 (CATHODE,ANODE_3), RN1.2 (1)
unnamed: IC4.7 (CATHODE,ANODE_4), RN1.1
unnamed: C8.2, U1.1 (C1+)
unnamed: C8.1, U1.3 (C1-)
unnamed: C9.1, U1.4 (C2+)
unnamed: C9.2, U1.5 (C2-)
unnamed: C2.2, U1.2 (V+)
unnamed: C10.2, U1.6 (V-)
unnamed: Q6.1 (B), R64.1
unnamed: Q7.1 (B), R65.1
unnamed: D100.A, Q7.3 (C), X7.3
unnamed: D101.A, Q6.3 (C), X7.1
ON/OFF: IC1.5 (EN), Q1.3 (C), R21.1, R28.1
PROG_RX0: IC3.2 ((RXD0/PCIN8)PE0), PROG.2 (D-)
PROG_TX0: IC3.3 ((TXD0)PE1), PROG.3 (D+)
R1IN: J1.3, U1.13 (R1IN)
RELAY_1: IC3.53 ((A8)PC0), R58.2
RELAY_2: IC3.54 ((A9)PC1), R59.2
RESET: IC3.30 (RESET), J2.5, PROG.1 (VCC), R41.1, S1.2
RS485_CTRL: IC3.76 ((AD2)PA2), U2.2 (/RE), U2.3 (DE)
RS485_RX: IC3.63 (PJ0(RXD3/PCINT9)), U2.1 (RO)
RS485_TX: IC3.64 (PJ1(TXD3/PCINT10)), U2.4 (DI)
SCK: IC3.20 ((SCK/PCINT1)PB1), J2.3, U5.5 (A4)
SCK_3V: SD1.5 (CLK(SCLK)), U5.15 (B4), WIFI.J18 (SCK)
SCL: IC3.43 ((SCL/INT0)PD0), R37.2, U3.10 (SCL), U6.6 (SCL)
SDA: IC3.44 ((SDA/INT1)PD1), R36.2, U3.9 (SDA), U6.5 (SDA)
SD_CS_3V: SD1.2 (CD/DAT3(!CS!)), U5.17 (B2)
SD_CS_5V: IC3.23 ((OC2A/PCINT4)PB4), R32.1, U5.3 (A2)
SD_DETECT: IC3.1 ((OC0B)PG5), R61.2, SD1.9 (!CARD)
T1OUT: J1.2, U1.14 (T1OUT)
VCCA: C16.2, DOV100.C, DOV101.C, DOV102.C, DOV103.C, FB2.1, IC2.8 (P$V+), R30.2, U3.8 (VDD)
WAKE_3V: R54.2, U5.13 (B6)
WAKE_5V: IC3.18 (PH6(OC2B)), U5.7 (A6)

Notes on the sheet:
3.3V Regulator
Power Supply
Undervoltage Lockout
5v SMPS
SD Card Module with Level Shifter
ATWINC1500 Module with Level Shifter
RS485 Circuit
RTC Circuit
Analog and Digital ground Isolation
Use diffrent fuse for RS485
Relay and Digital Outputs
Digital Inputs
4-20mA Circuit
HM-10 BLE Module
DC Motor Speed Controller

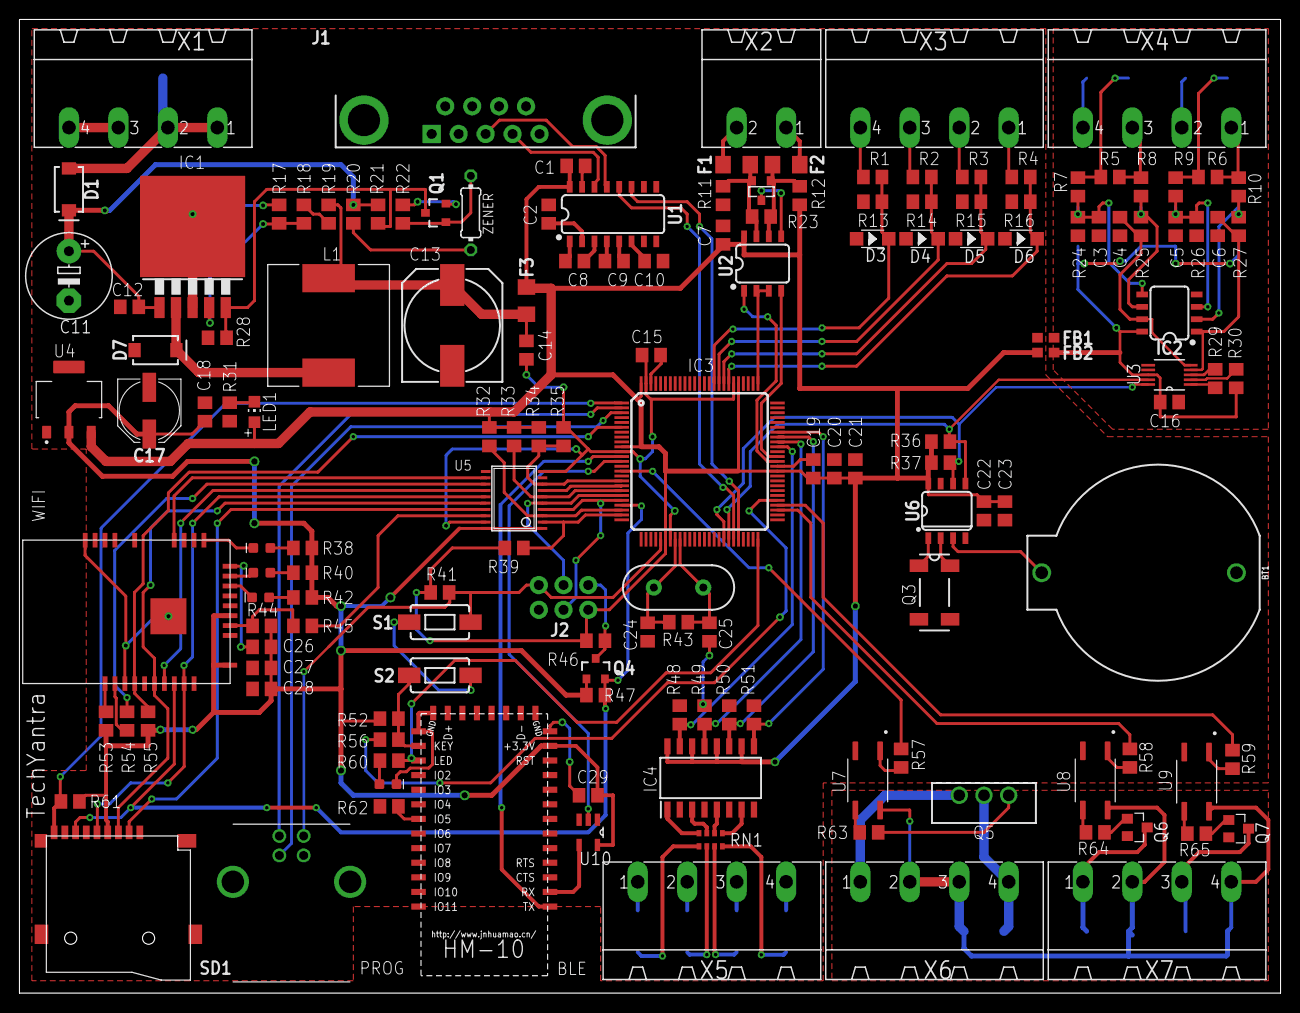
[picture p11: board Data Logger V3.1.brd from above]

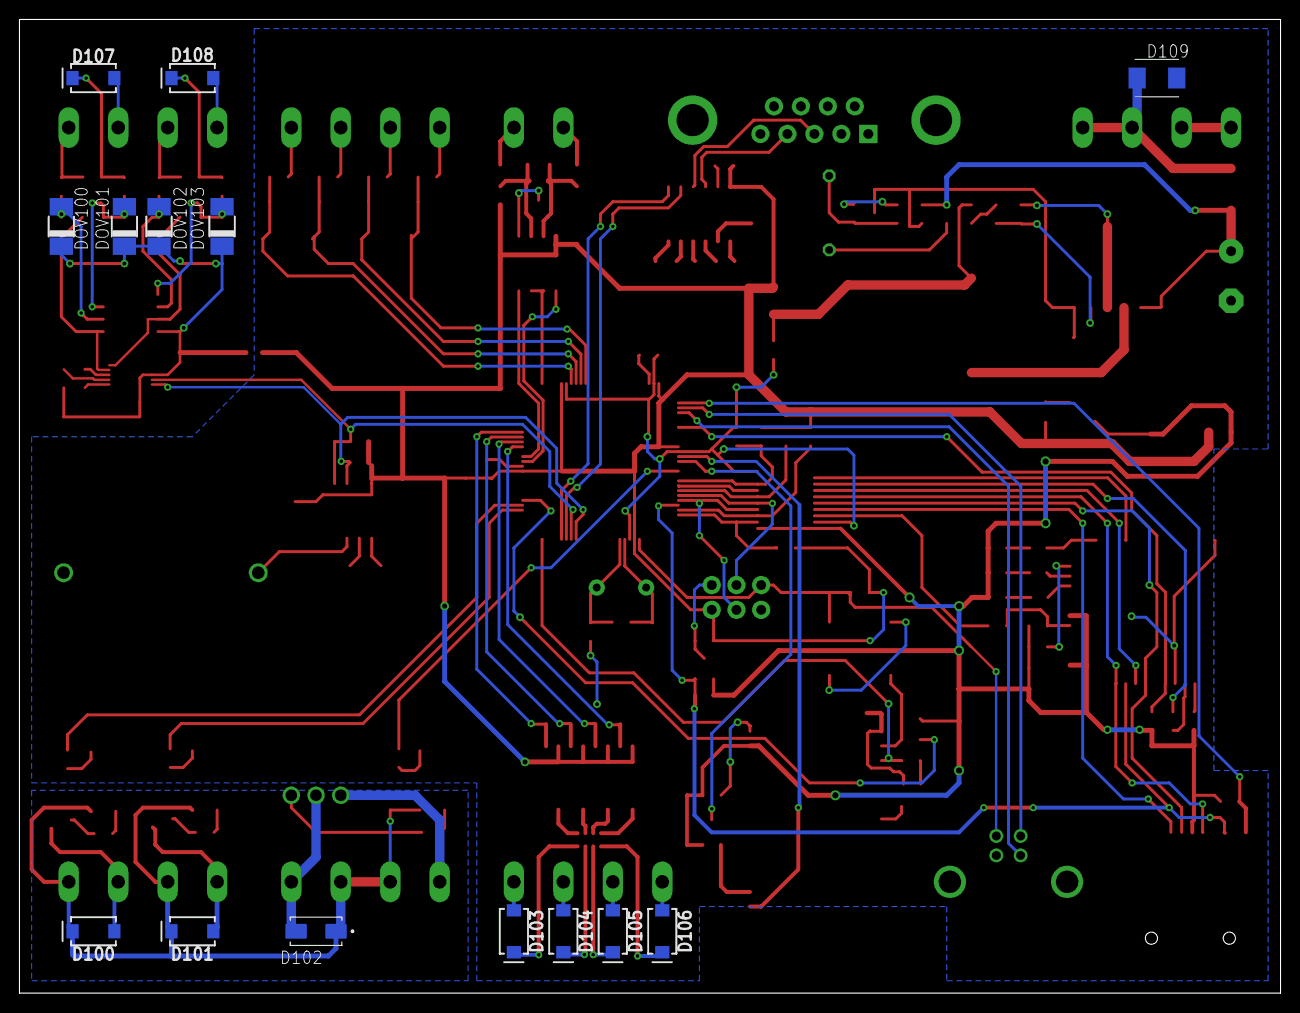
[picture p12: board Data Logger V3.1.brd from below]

Board: 2 copper layers, 129.5 x 100.0 mm, 165 parts (14 on the bottom side), 133 nets.

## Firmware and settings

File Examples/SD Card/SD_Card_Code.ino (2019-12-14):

/*
 * 
 * Header files
 */
#include <Wire.h>                 //Library for I2C Interface
#include "DS1307.h"               //Library for DS1307 IC (RTC)
#include <Adafruit_ADS1015.h>     //Library for ADS1115 IC (16 Bit ADC)
#include <WiFi101.h>              //Library for ATWINC1510 WiFi module
#include <SPI.h>                  //Library for SPI Interface
#include "SdFat.h"                //Library for SD Card

/*
 * 
 * Defining objects of diffrent class
 */
DS1307 clock;                     //Defining object of DS1307 class
Adafruit_ADS1115 ads;             //Defining object of Adafruit_ADS1115 class
WiFiClient client;                //Defining object of WiFiClient class
File myFile;                      //Defining object of myFile class
SdFat SD;                         //Defining object of SdFat class 


/*
 * 
 * Variable declaration
 */
//General variables
uint16_t Analog_Value = 0; 
bool Status = 0;


//Variables for 0-10v Analog Input sensor
static const uint8_t Analog_Input_Pins[] = {A12,A13,A14,A15};
float Analog_Voltage = 0; 


//Variables for Relay Driver
const byte Relay_1_Pin = 36;
const byte Relay_2_Pin = 37;


//Variables for BLE Module
const byte BLE_Status_Pin = 38;


//Variables for SD card Module
const byte SD_Status_Pin = 4;
char File_Name[20] = "Data1.csv";
char Temp_Buffer[10];
char SD_DataBuffer[100];


//Variables for ADC
int16_t adc0, adc1;
float Voltage;


//Variables for pin change interrupt program
volatile uint32_t Pul_PJ3=0, Pul_PJ4=0, Pul_PJ5=0, Pul_PJ6=0;
uint32_t Pulse_count[4];   


//Variables for WiFi module
byte status;
int  Result;
char hostName[20]     = "www.google.com";


//Digital pins for WIFI  
const byte WIFI_Reset_Pin    =   8;  
const byte WIFI_ChipSel_Pin  =   53; 
const byte WIFI_IRQ_Pin      =   2; 


//Wifi credentials
char ssid[] = "Piyush";      // your network SSID (name)
char pass[] = "Piyush1234";    // your network password (use for WPA, or use as key for WEP)





/*
 * Setup Code
 */
void setup() 
{
  //Initializing UART0
  Serial.begin(115200);

  Serial.println("System Reset");
  Serial.println();


  //Initializing Digital Inputs for Relay
  pinMode(Relay_1_Pin, OUTPUT);           // set pin to input
  pinMode(Relay_2_Pin, OUTPUT);           // set pin to input


  //Initializing RTC and setting RTC Parameters
  clock.begin();
  clock.fillByYMD(2019,5,4);              //Jan 19,2013
  clock.fillByHMS(6,18,0);                //6:08:0"
  clock.fillDayOfWeek(SAT);               //Saturday
  clock.setTime();                        //write RTC parameters to chip
  

  //Initializing ADS1115
  ads.begin();


  //Initializing PCINT functionality on PCINT12, PCINT13, PCINT14, PCINT15
  sei();                                  // turn on global interrupts
  PCICR =  (1 << PCIE1);                  // set PCIE1 PCMSK1 scan
  PCMSK1 = (1 << PCINT12) | (1 << PCINT13) | (1 << PCINT14) | (1 << PCINT15) ;   // set PCINT12, PCINT13, PCINT14, PCINT15 to trigger an interrupt on state change 

  //Initializing SD card
  Serial.print("Initializing SD card...");
  
  if (!SD.begin(10)) 
  {
    Serial.println("initialization failed!");
    while (1);
  }
  Serial.println("initialization done.");
  Serial.println();

  //Initializing WiFi module and connecting to WiFi module
  Connect_To_WiFi_Network(); 

}



void loop() 
{
  //Clearing RS232 DataBuffer
  strcpy(SD_DataBuffer, "");

  //Reading RTC parameters
  Read_RTC_Parameters();
  
  //Reading 0-10v Analog Input Channel
  Read_Analog_Input_Channel();

  //Reading 0-10v Digital Input Channel
  Read_Pulse_Count_Digital_Input();

  //Readings 4-20mA sensor
  Read_4_20_mA_Sensor();
  
  //Reading Status of BLE module
  Read_BLE_Status();

  //Reading Status of WIFI module
  Read_WIFI_Status();

  //Reading Status of SD card module
  Read_SD_Status();

  //Reading 0-10v Digital Input Channel
  Read_Relay_Status();

  //Storing Data in SD card in form of CSV file
  Storing_Data_To_SD_Card();

  Serial.println(SD_DataBuffer);
  Serial.println();

  delay(10000);
}


/*
 * Function to read RTC parameters
 * MM/DD/YYYY,HH:MM:SS,DAY,
 */
void Read_RTC_Parameters()
{
  
  clock.getTime();                                //Getting time from DS1307 RTC IC
  itoa(clock.month, Temp_Buffer, 10);             //Converting integer value to ascii charecter and storing it in Temp_Buffer 
  strcat(SD_DataBuffer, Temp_Buffer);             //Storing temperory buffer in SD_DataBuffer
  strcpy(Temp_Buffer, "");                        //Clearing temperory buffer to store new analog value
  strcat(SD_DataBuffer, "/");                     //Including / in SD_DataBuffer

  itoa(clock.dayOfMonth, Temp_Buffer, 10);
  strcat(SD_DataBuffer, Temp_Buffer);
  strcpy(Temp_Buffer, "");
  strcat(SD_DataBuffer, "/");

  itoa(clock.year+2000, Temp_Buffer, 10);
  strcat(SD_DataBuffer, Temp_Buffer);
  strcpy(Temp_Buffer, "");
  strcat(SD_DataBuffer, ",");

  itoa(clock.hour, Temp_Buffer, 10);
  strcat(SD_DataBuffer, Temp_Buffer);
  strcpy(Temp_Buffer, "");
  strcat(SD_DataBuffer, ":");

  itoa(clock.minute, Temp_Buffer, 10);
  strcat(SD_DataBuffer, Temp_Buffer);
  strcpy(Temp_Buffer, "");
  strcat(SD_DataBuffer, ":");

  itoa(clock.second, Temp_Buffer, 10);
  strcat(SD_DataBuffer, Temp_Buffer);
  strcpy(Temp_Buffer, "");
  strcat(SD_DataBuffer, ",");

  switch (clock.dayOfWeek)
  {
    case MON:
      strcat(SD_DataBuffer, "MON,");
      break;
    case TUE:
      strcat(SD_DataBuffer, "TUE,");
      break;
    case WED:
      strcat(SD_DataBuffer, "WED,");
      break;
    case THU:
      strcat(SD_DataBuffer, "THU,");
      break;
    case FRI:
      strcat(SD_DataBuffer, "FRI,");
      break;
    case SAT:
      strcat(SD_DataBuffer, "SAT,");
      break;
    case SUN:
      strcat(SD_DataBuffer, "SUN,");
      break;
  }
}


/*
 * Function to read 0-10v Analog Value
 * HH:MM:SS,MM/DD/YYYY,DAY,A1,A2,A3,A4,
 */
void Read_Analog_Input_Channel()
{
  for(uint8_t i = 0; i < 4; i++)
  {
    //Reading Analog input channel
    Analog_Value = analogRead(Analog_Input_Pins[i]); 
               
    //Converting Analog value to voltage
    Analog_Voltage = Analog_Value * 0.0048828 * 2;

    //Converting float value to charecter and storing it in temoprary buffer
    dtostrf(Analog_Voltage, 6, 4, Temp_Buffer);                  

    //Storing temperory buffer in SD_DataBuffer
    strcat(SD_DataBuffer, Temp_Buffer);   

    //Clearing temperory buffer to store new analog value
    strcpy(Temp_Buffer, "");

    //Including comma in SD_DataBuffer
    strcat(SD_DataBuffer, ",");                                
  }
}


/*
 * Interrupt Service Routine to count pulses on PCINT12, PCINT13, PCINT14, PCINT15 
 * (Pin Number 66, 67, 68, 69 on Atmega256)
 * Store count values in Count[0], Count[1], Count[2], Count[3]
 */
ISR (PCINT1_vect)                   
{
  //Checking if their is logic high on pin no 3 of Port J (pcint12)
  //If logic high is present then increment the count
  if( bit_is_set(PINJ,3) )
  {
      Pul_PJ3++;                  
      Pulse_count[0] = Pul_PJ3;   
      //Serial.println(Pul_PJ3);
  }

  //Checking if their is logic high on pin no 4 of Port J (PCINT13)
  //If logic high is present then increment the count 
  if( bit_is_set(PINJ,4) )
  {
      Pul_PJ4++;                 
      Pulse_count[1] = Pul_PJ4; 
      //Serial.println(Pul_PJ4);
  }

  //Checking if their is logic high on pin no 5 of Port J (PCINT14)
  //If logic high is present then increment the count 
  if( bit_is_set(PINJ,5) )
  {
      Pul_PJ5++;                  
      Pulse_count[2] = Pul_PJ5;  
      //Serial.println(Pul_PJ5); 
  }

  //Checking if their is logic high on pin no 6 of Port J (PCINT15)
  //If logic high is present then increment the count 
  if( bit_is_set(PINJ,6) )
  {
      Pul_PJ6++;                  
      Pulse_count[3] = Pul_PJ6;  
      //Serial.println(Pul_PJ6);
  }
}


/*
 * Function to construct string for external pulses 
 * HH:MM:SS,MM/DD/YYYY,DAY,A1,A2,A3,A4,D1,D2,D3,D4,
 */
//Function to construct string for external pulses 
void Read_Pulse_Count_Digital_Input()
{
  for(uint8_t i = 0; i < 4; i++)
  {
    //Converting float value to charecter and storing it in temoprary buffer
    itoa(Pulse_count[i], Temp_Buffer, 10);
  
    //Storing temperory buffer in SD_DataBuffer
    strcat(SD_DataBuffer, Temp_Buffer);
  
    //Clearing temperory buffer to store new analog value
    strcpy(Temp_Buffer, "");
  
    //Including comma in SD_DataBuffer
    strcat(SD_DataBuffer, ",");
  } 
}


/*
 * Function to read Read_4_20_mA_Sensor
 * HH:MM:SS,MM/DD/YYYY,DAY,A1,A2,A3,A4,D1,D2,D3,D4,S1,S2,
 */
//Function to read Read_4_20_mA_Sensor
void Read_4_20_mA_Sensor()
{
  //Reading 4-20 mA Sensor (Channel 1)
  adc0 = ads.readADC_SingleEnded(0);

  Voltage = ((5 * adc0) * 0.00003761);

  //Converting float value to charecter and storing it in temoprary buffer
  dtostrf(Voltage, 6, 4, Temp_Buffer);

  //Storing temperory buffer in SD_DataBuffer
  strcat(SD_DataBuffer, Temp_Buffer);

  //Clearing temperory buffer to store new analog value
  strcpy(Temp_Buffer, "");

  //Including comma in SD_DataBuffer
  strcat(SD_DataBuffer, ",");


  //Reading 4-20 mA Sensor (Channel 2)
  adc1 = ads.readADC_SingleEnded(1);
  
  Voltage = ((5 * adc1) * 0.00003761);

  //Converting float value to charecter and storing it in temoprary buffer
  dtostrf(Voltage, 6, 4, Temp_Buffer);

  //Storing temperory buffer in SD_DataBuffer
  strcat(SD_DataBuffer, Temp_Buffer);

  //Clearing temperory buffer to store new analog value
  strcpy(Temp_Buffer, "");

  //Including comma in SD_DataBuffer
  strcat(SD_DataBuffer, ",");
}


/*
 * Function to read status of BLE module
 * HH:MM:SS,MM/DD/YYYY,DAY,A1,A2,A3,A4,D1,D2,D3,D4,S1,S2,STA_BLE,
 */
void Read_BLE_Status()
{
  //Reading status of Relay 1
  Status = digitalRead(BLE_Status_Pin);

  if(Status == 1)
  {
    strcat(SD_DataBuffer, "BLE Connected");
  }
  else
  {
    strcat(SD_DataBuffer, "BLE Disconnected");
  }
  
  //Including comma in SD_DataBuffer
  strcat(SD_DataBuffer, ",");
}


/*
 * Function to read status of WiFi module
 * HH:MM:SS,MM/DD/YYYY,DAY,A1,A2,A3,A4,D1,D2,D3,D4,S1,S2,STA_BLE,STA_WiFi,
 */
//Function to check status of WIFI Network
void Read_WIFI_Status()
{    
  if(WiFi.status() == WL_CONNECTED )
  {
    strcat(SD_DataBuffer, "WiFi Connected,");
  }
  else
  {
    strcat(SD_DataBuffer, "WiFi Disconnected,");
  }
}


/*
 * Function to read status of wiFi module
 * HH:MM:SS,MM/DD/YYYY,DAY,A1,A2,A3,A4,D1,D2,D3,D4,S1,S2,STA_BLE,STA_WiFi,STA_SD
 */
//Function to read BLE status
void Read_SD_Status()
{
  
  //Reading status of Relay 1
  Status = digitalRead(SD_Status_Pin);

  if(Status == 1)
  {
    strcat(SD_DataBuffer, "SD NOT Present");
  }
  else
  {
    strcat(SD_DataBuffer, "SD Present");
  }
  
  //Including comma in SD_DataBuffer
  strcat(SD_DataBuffer, ",");
}


/*
 * Function to read Relay State
 * HH:MM:SS,MM/DD/YYYY,DAY,A1,A2,A3,A4,D1,D2,D3,D4,S1,S2,STA_BLE,STA_WiFi,STA_SD,R1,R2
 */
void Read_Relay_Status()
{
  //Reading status of Relay 1
  Status = digitalRead(Relay_1_Pin);

  if(Status == 1)
  {
    strcat(SD_DataBuffer, "ON");
  }
  else
  {
    strcat(SD_DataBuffer, "OFF");
  }
  
  //Including comma in SD_DataBuffer
  strcat(SD_DataBuffer, ",");

  //Reading status of Relay 2
  Status = digitalRead(Relay_2_Pin);

  if(Status == 1)
  {
    strcat(SD_DataBuffer, "ON");
  }
  else
  {
    strcat(SD_DataBuffer, "OFF");
  }
  
  //Including comma in SD_DataBuffer
  strcat(SD_DataBuffer, ",");
}


/*
 * Function to store dataLogger parameters to SD card
 * DataLogger Parameter : HH:MM:SS,MM/DD/YYYY,DAY,A1,A2,A3,A4,D1,D2,D3,D4,S1,S2,STA_BLE,STA_WiFi,STA_SD,R1,R2
 * Folder_Name = YYYY/MM
 * File_Name = YYYY/MM/DD_MM_YYYY.csv
 */
void Storing_Data_To_SD_Card()
{
  //Open the file note that only one file can be open at a time,
  //so you have to close this one before opening another

  myFile = SD.open(File_Name, FILE_WRITE);
  
  //If the file opened okay, write to it:
  if(myFile)
  {
    Serial.println();
    Serial.print("Writing to Data1.csv...");

    myFile.println(SD_DataBuffer);

    //close the file
    myFile.close();
    Serial.println("done.");
  }
  else
  {
    //if the file did't open, print an error
    Serial.println("error opening Data1.txt");
  }
}


/*
 * Function to connect Wifi Module
 */
void Connect_To_WiFi_Network()
{
   //Defining Local variable
   byte WiFi_Connection_Attempt_Count = 0;
   byte Available_Network_Count = 0;
  
   //Defining ChipSelect, Interrupt and Reset pin of Wifi module
   WiFi.setPins(WIFI_ChipSel_Pin, WIFI_IRQ_Pin, WIFI_Reset_Pin);
  
   
   Serial.println("** Scanning Available Networks **");

   //Scanning all the available WiFi networks
   Available_Network_Count = WiFi.scanNetworks();
  
   //Displaying the number of available networks
   Serial.print("Available Network: ");
   Serial.println(Available_Network_Count);
   Serial.println();

   //Displaying Parameters of available WiFi Network 
   for(uint8_t i = 0; i < Available_Network_Count; i++) 
   { 
     //Displaying number of network       
     Serial.print(i);
     Serial.print(") ");

     //Displaying SSID of WiFi Network
     Serial.print("SSID: ");
     Serial.println(WiFi.SSID(i));
     
     //Displaying Recieved Signal Strength of WiFi Network
     Serial.print("   Signal Strength: ");
     Serial.print(WiFi.RSSI(i));
     Serial.println(" dBm");

     //Displaying type of encryption for WiFi Network
     Serial.print("   Encryption Type: ");
     Serial.println(WiFi.encryptionType(i));

     Serial.println();
   }
   

  //Connecting to predefined Wifi Network
  if(WiFi.status() != WL_CONNECTED)
  {
    WiFi_Connection_Attempt_Count = 0;
  
     //Stay in loop if not connected to WiFi Network and if connection attempts is less than 5
     while (WiFi.status() != WL_CONNECTED && WiFi_Connection_Attempt_Count < 5 ) 
     {       
       Serial.print("Attempting to connect to SSID: ");
       Serial.println(ssid);
  
       //Connecting to WiFi network
       status = WiFi.begin(ssid, pass);
       delay(5000);
  
       //Incrementing count
       WiFi_Connection_Attempt_Count++;
     }
  }

   //Enter only if succesfully connected to predefined Network     
   if(WiFi.status() == WL_CONNECTED)
   {
     Serial.println();
     Serial.println("*****Connected to WiFi Network*****");

     //Displaying the status of WiFi network
     printWiFiStatus();
       
     Serial.print("Ping Google: "); 
     
     //Trying to connect to googles server to check internet is available or not
     Result = WiFi.ping(hostName); 
     
     if(Result >= 0) 
     {
       Serial.print("SUCCESS! RTT = ");

       //Displaing the time taken to get the responce from the google server
       Serial.print(Result);
       Serial.println(" ms");
       Serial.println();
     }
     else 
     {
       Serial.print("FAILED! Error code: ");
       Serial.println(Result);
       Serial.println();
     }
    }
    else
    {
      Serial.print("Failed to connect!");
      Serial.println();

      //Try to connect one more time
      Connect_To_WiFi_Network();
    }
}


/*
 * Function to print parameters of connected SSID
 */
void printWiFiStatus() 
{//Here we are printing the WIFI status
  
  // print the SSID of the network you're attached to:
  Serial.print("SSID: ");
  Serial.println(WiFi.SSID());

  // print your WiFi shield's IP address:
  IPAddress ip = WiFi.localIP();
  Serial.print("IP Address: ");
  Serial.println(ip);

  // print the received signal strength:
  long rssi = WiFi.RSSI();
  Serial.print("signal strength (RSSI):");
  Serial.print(rssi);
  Serial.println(" dBm");
}

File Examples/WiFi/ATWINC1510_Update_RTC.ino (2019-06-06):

/*
 * Descreption :
 * 
 * This code enables the WiFi module to conncet to the predefined
 * WiFi network and later it program the wrong date inside the RTC.
 * 
 * After that it fetches the Time and Date from the cloud by using 
 * two diffrent API links by sending HTTP request to Thing Speak.com
 * 
 * 1. GET https://api.thingspeak.com/apps/thinghttp/send_request?api_key=SYHSST4VZ9KNQR1L
 * 2. GET https://api.thingspeak.com/apps/thinghttp/send_request?api_key=9QT023WUBZ6XCMSL
 * 
 * After fetching the correct date and time It program it in RTC module
 * 
 * Later it displays the RTC parameters on serial terminal with a delay of one sec.
 */


/*
 * 
 * Header files 
 */
#include <WiFi101.h>              //Library for ATWINC1510 WiFi module
#include <SPI.h>                  //Library for SPI Interface
#include <Wire.h>                 //Library for I2C interface
#include "DS1307.h"               //Library for DS1307 I2C IC


/*
 * 
 * Defining objects of diffrent class
 */
WiFiClient client;                //Defining object of WiFiClient class
DS1307 clock;                     //Defining object of DS1307 class


/*
 * 
 * Variables for WiFi module
 */
byte status;
int  Result;
char hostName[20] = "www.google.com";

//Digital pins for WIFI  
const byte WIFI_Reset_Pin    =   8;                             //Defining Reset pin for WiFi module
const byte WIFI_ChipSel_Pin  =   53;                            //Defining ChipSelect pin for WiFi module
const byte WIFI_IRQ_Pin      =   2;                             //Defining Interrupt pin for WiFi module

//Wifi credentials
const char ssid[] = "Piyush";                                   //Defining SSID of WiFi Network
const char pass[] = "Piyush1234";                               //Defining Password of WiFi Network

//Defining Buffers  
char API_Responce[50]               = {0};                      //Defining buffer to store API responce
char Temp_Buffer[10]                = {0};                      //Defining buffer for general purpose
char ThingSpeak_API_String[90]      = {0};                      //Defining buffer to store constructed api string
const char Date_APIKey[]            = "SYHSST4VZ9KNQR1L";       //Defining API key to fetch Date from cloud
const char Time_APIKey[]            = "9QT023WUBZ6XCMSL";       //Defining API key to fetch Time from cloud
const char Date_Time_API_String[70] = "GET https://api.thingspeak.com/apps/thinghttp/send_request?api_key=";        //Defining API link to fetch Date and Time from cloud




/*
 * 
 * Setup
 */
void setup() 
{
  //Initializing UART0 at a baud rate of 115200
  Serial.begin(115200);

  //Displaying messege to indicate system is reset
  Serial.println("System Reset");
  Serial.println();


  //Initializing WiFi module and connecting to WiFi module
  Connect_To_WiFi_Network();


  //Initializing RTC IC and setting the RTC parameters
  clock.begin();
  clock.fillByYMD(2013,1,19);       //Setting Year, Month, and Date for RTC
  clock.fillByHMS(7,28,30);         //Setting Hour, Min and Sec for RTC
  clock.fillDayOfWeek(SAT);         //Setting Day for RTC
  clock.setTime();                  //Sending RTC parameters to RTC


  //Displaying the RTC parameters before updating them
  Serial.println();
  Serial.println();
  Serial.println("*****RTC parameters before updating*****");
  printTime();
  Serial.println("               **********               ");
  Serial.println();
}

/*
 * 
 * Main Loop
 */
void loop() 
{
  Serial.println();

  Serial.print("********** Recieving data from internet *********");

  //Fetching Time from Cloud using API
  Fetch_API_Data(Time_APIKey);


  //Updating RTC time with the time fetched from cloud
  Updating_RTC_Time();


  //Clearing API responce Buffer
  for(uint8_t i=0; i<50;i++)
  {
    API_Responce[i]  =  0;
  }
  
  delay(1000);


  //Fetching Date from Cloud using API
  Fetch_API_Data(Date_APIKey); 


  //Updating RTC Date and Day with the Date and Day fetched from cloud
  Updating_RTC_Date();


  //Clearing API responce Buffer
  for(uint8_t i=0; i<50;i++)
  {
    API_Responce[i]  =  0;
  }
  
  Serial.println("           ********** Done *********           ");
  Serial.println();


  //Displaying the RTC parameters After updating them
  Serial.println();
  Serial.println();
  Serial.println("*****RTC parameters After updating*****");
  Serial.println();
  
  while(1)
  {
    //Displaying RTC parameters on Serial monitor
    printTime();

    delay(1000);
  }
}




/*
 * Function to connect Wifi Module
 */
void Connect_To_WiFi_Network()
{
   //Defining Local variable
   byte WiFi_Connection_Attempt_Count = 0;

   //Defining pin number for chipselect, Interrupt and reset pin of WiFi module
   WiFi.setPins(WIFI_ChipSel_Pin, WIFI_IRQ_Pin, WIFI_Reset_Pin);

  
   Serial.println("** Scanning Available Networks **");

   //Scanning all the available network
   byte Available_Network_Count = WiFi.scanNetworks();
  
   //Displaying all the available WiFi network
   Serial.print("Total Available Networks: ");
   Serial.println(Available_Network_Count);
   Serial.println();
  
   //Displaying Parameters of available WiFi Network 
   for(uint8_t i = 0; i < Available_Network_Count; i++) 
   { 
     //Displaying number of network       
     Serial.print(i);
     Serial.print(") ");

     //Displaying SSID of WiFi Network
     Serial.print("SSID: ");
     Serial.println(WiFi.SSID(i));
     
     //Displaying Recieved Signal Strength of WiFi Network
     Serial.print("   Signal Strength: ");
     Serial.print(WiFi.RSSI(i));
     Serial.println(" dBm");

     //Displaying type of encryption for WiFi Network
     Serial.print("   Encryption Type: ");
     Serial.println(WiFi.encryptionType(i));

     Serial.println();
   }
   
   
  
   //Connecting to predefined SSID (Maximum 5 Attempts)
   if(WiFi.status() != WL_CONNECTED)
   {
     //Initializing the count
     WiFi_Connection_Attempt_Count = 0;

     //Stay in loop if not connected to WiFi Network and if connection attempts is less than 5
     while (WiFi.status() != WL_CONNECTED && WiFi_Connection_Attempt_Count < 5 ) 
     {       
       Serial.print("Attempting to connect to SSID: ");
       Serial.println(ssid);

       //Connecting to WiFi network
       status = WiFi.begin(ssid, pass);
       delay(5000);

       //Incrementing count
       WiFi_Connection_Attempt_Count++;
     }
   }


   //Enter only if succesfully connected to predefined Network     
   if(WiFi.status() == WL_CONNECTED)
   {
     Serial.println();
     Serial.println("*****Connected to WiFi Network*****");

     //Displaying the status of WiFi network
     printWiFiStatus();
       
     Serial.print("Ping Google: "); 
     
     //Trying to connect to googles server to check internet is available or not
     Result = WiFi.ping(hostName); 
     
     if(Result >= 0) 
     {
       Serial.print("SUCCESS! RTT = ");
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

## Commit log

2019-06-06 Create gerber
2019-06-06 Create gerber file
2019-06-06 Create drill
2019-06-06 Create 2. Atmega256 Circuit
2019-06-06 Create Power Supply Descreption
2019-06-06 Update Power Supply Descreption

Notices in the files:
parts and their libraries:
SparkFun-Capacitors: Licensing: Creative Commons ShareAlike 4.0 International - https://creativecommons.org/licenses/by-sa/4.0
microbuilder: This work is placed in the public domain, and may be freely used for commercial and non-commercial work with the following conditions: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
